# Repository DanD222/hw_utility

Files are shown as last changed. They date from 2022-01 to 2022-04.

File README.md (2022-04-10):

# PCB design for utility module
Utility hardware design for Audio Module, Analog Inputs, I2C/SPI sensors, RS232 and some digitial inputs. 
- PCB assembly files are below pcb/assembly/
- PDF Schematic is below pcb/pdf_exports/ 

## Components
- STM32F103 Bluepill board.
- 9 to 30V DC DC power supply.
- PAM8302AAS  audio amplifier connected to STM32F1 PWM output
- Screwterminal for loudspeaker
- RJ45 connector for sensing e.g. gear, flaps, airbrakes postion
- RJ45 connector for CAN Interface and CAN transceiver
- RJ12 connector with analog and digital inputs
- 1.27mm pitch header for external I2C devices
- 1.27mm pitch header for RS232 and SPI interface

## Pictures
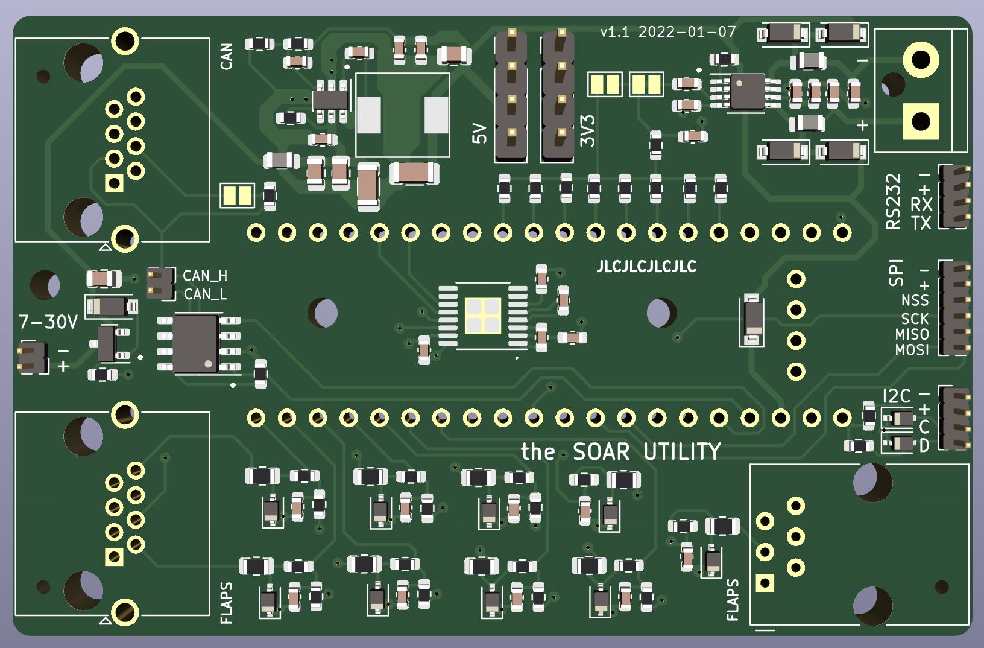
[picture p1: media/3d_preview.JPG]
3D Preview


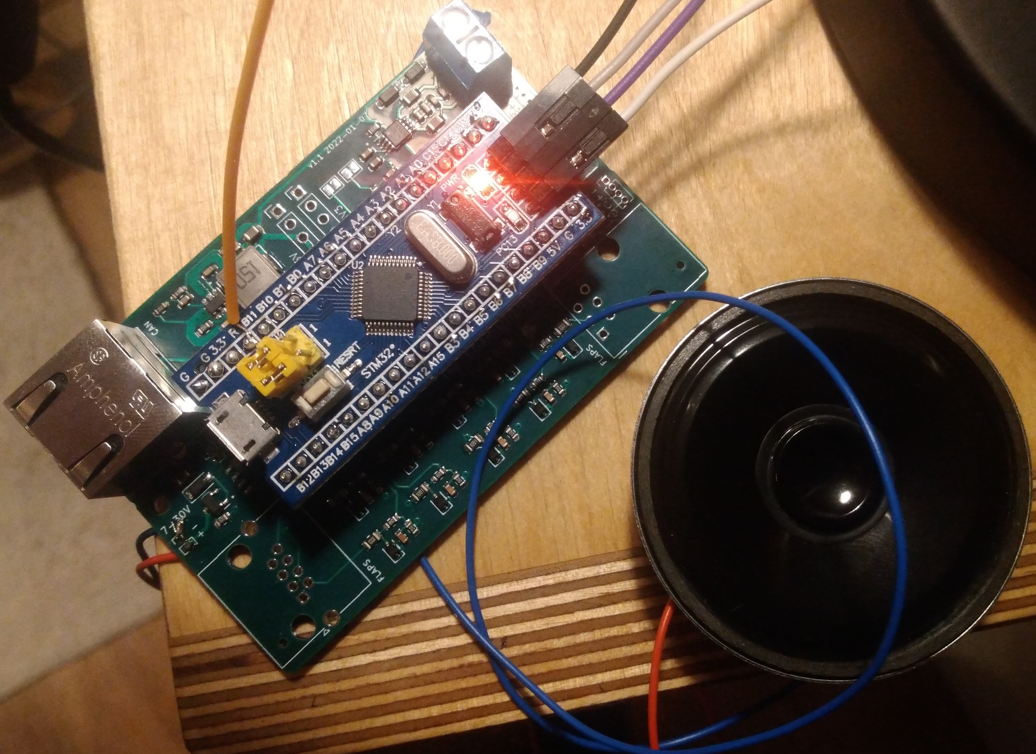
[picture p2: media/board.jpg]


## Improvements for next version
- External connectors for voltage / I2C / RS232 are tiny.  Increase size to e.g. 2.54mm pitch or chose a different connector.
- Make external i2c sensor voltage switchable to be able to perform a hard sensor reset. 
- Replace C32 47uF with a sufficient voltage rating. The used one is only specified for up to 10V!

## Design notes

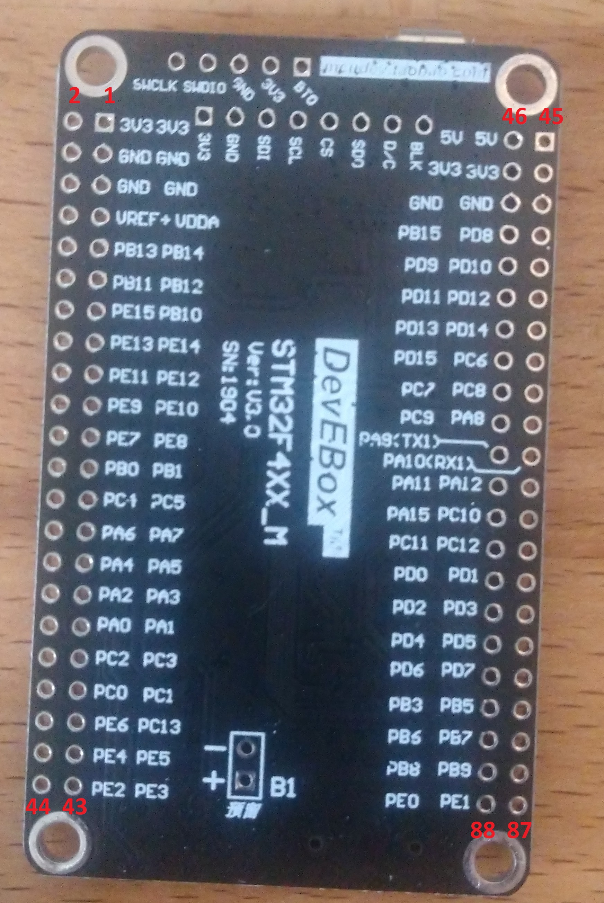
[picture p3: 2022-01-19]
parts/pinout.jpg

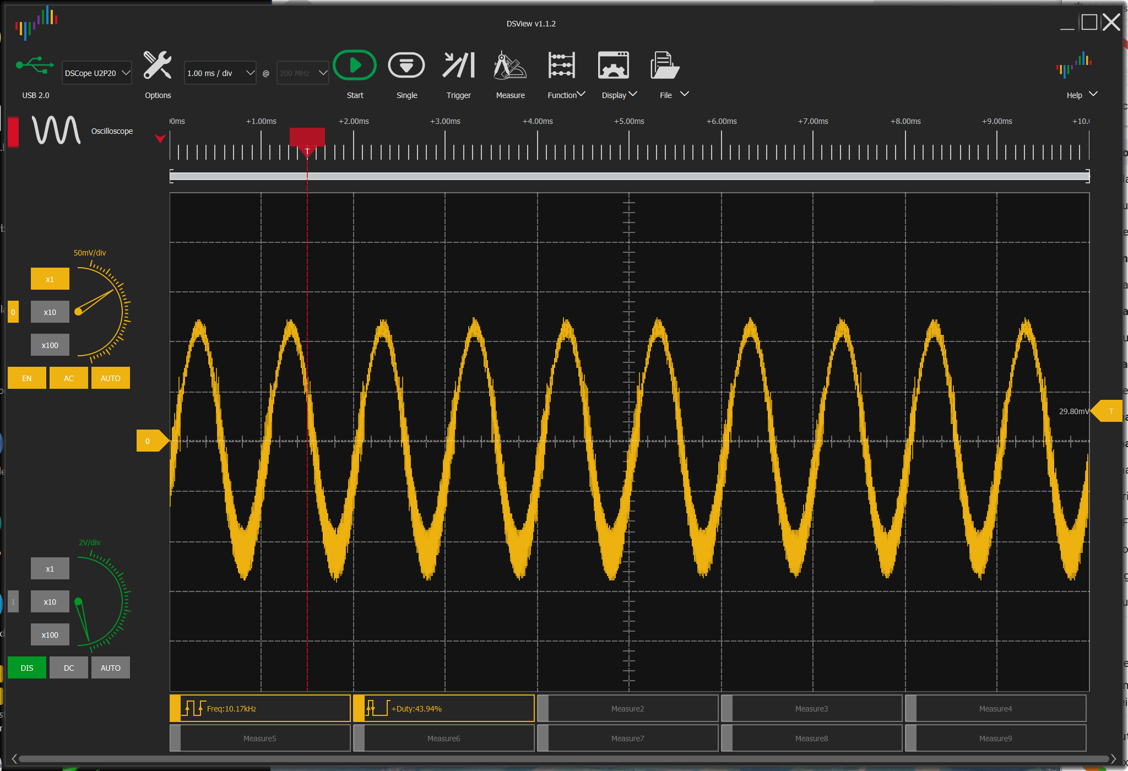
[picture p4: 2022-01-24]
media/1Khz_Sine_with_PWM.png

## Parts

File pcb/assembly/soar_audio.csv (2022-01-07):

Comment | Designator | Footprint | LCSC Part Number
10u | C1,C2,C9 | Capacitor_SMD:C_0805_2012Metric | C440198
10u | C13 | Capacitor_SMD:C_0603_1608Metric | C19702
220p | C15,C16 | Capacitor_SMD:C_0603_1608Metric | C1603
2n7 | C23 | Capacitor_SMD:C_0603_1608Metric | C1609
100n | C3,C7,C10,C24,C25,C27,C28,C29 | Capacitor_SMD:C_0603_1608Metric | C14663
100p | C30 | Capacitor_SMD:C_0603_1608Metric | C14858
47u | C31,C32 | Capacitor_SMD:C_1206_3216Metric | C96123
2u2 | C4 | Capacitor_SMD:C_0805_2012Metric | C49217
10n | C5,C6,C17,C18,C19,C20,C21,C22,C26 | Capacitor_SMD:C_0603_1608Metric | C57112
1u | C8,C11,C12,C14 | Capacitor_SMD:C_0603_1608Metric | C15849
D_MM1Z15 | D1 | Diode_SMD:D_SOD-123 | C86235
D_TVS | D2,D4,D5,D6,D12,D13,D14,D15,D16,D17,D21 | Diode_SMD:D_SOD-323 | C51450
D_B5819W | D7,D8,D9,D10,D11 | Diode_SMD:D_SOD-123 | C8598
Ferrite | FB1,FB3,FB4 | Inductor_SMD:L_0805_2012Metric | C1017
RJ45-FLAPS | J1 | RJ45_Amphenol_RJHSE5380
HEADER_6 | J11 | Connector_PinHeader_1.27mm:PinHeader_1x06_P1.27mm_Vertical
RJ12-FLAPS | J2 | Connector_RJ:RJ12_Amphenol_54601
HEADER_4 | J3,J6 | Connector_PinHeader_1.27mm:PinHeader_1x04_P1.27mm_Vertical
Screw_Terminal_01x02 | J4 | TerminalBlock:TerminalBlock_bornier-2_P5.08mm
RJ45-CAN | J5 | RJ45_Amphenol_RJHSE5380
HEADER_2 | J7,J10 | Connector_PinHeader_1.27mm:PinHeader_1x02_P1.27mm_Vertical
HEADER_4 | J8,J9 | Connector_PinHeader_2.54mm:PinHeader_1x04_P2.54mm_Vertical
Jumper_Bridged | JP1 | Jumper:SolderJumper-2_P1.3mm_Bridged_Pad1.0x1.5mm
Jumper_Open | JP2,JP5 | Jumper:SolderJumper-2_P1.3mm_Open_Pad1.0x1.5mm
15u | L1 | OWN_PARTS:SLO0630H | C182182
AO3401A | Q1 | Package_TO_SOT_SMD:SOT-23 | C15127
100k | R1,R4,R11,R19,R24,R25,R28,R31,R34 | Resistor_SMD:R_0603_1608Metric | C25803
0R | R10 | Resistor_SMD:R_0603_1608Metric | C21189
10k | R13 | Resistor_SMD:R_0603_1608Metric | C25804
R120 | R14 | Resistor_SMD:R_0603_1608Metric | C22787
4k7 | R15,R16 | Resistor_SMD:R_0603_1608Metric | C23162
1k | R2,R7,R17,R20,R21,R26,R29,R32,R44 | Resistor_SMD:R_0805_2012Metric | C17513
1k | R3,R8,R18,R22,R23,R27,R30,R33,R45 | Resistor_SMD:R_0603_1608Metric | C21190
120k | R35,R36 | Resistor_SMD:R_0603_1608Metric | C25808
56k | R37 | Resistor_SMD:R_0603_1608Metric | C23206
30k | R38 | Resistor_SMD:R_0603_1608Metric | C22984
15k | R39 | Resistor_SMD:R_0603_1608Metric | C22809
7k5 | R40 | Resistor_SMD:R_0603_1608Metric | C23234
3k6 | R41 | Resistor_SMD:R_0603_1608Metric | C22980
1k8 | R42 | Resistor_SMD:R_0603_1608Metric | C4177
105k | R5 | Resistor_SMD:R_0603_1608Metric | C16840
20k | R6 | Resistor_SMD:R_0603_1608Metric | C4184
68k | R9 | Resistor_SMD:R_0603_1608Metric | C23231
SCT2400 | U1 | Package_TO_SOT_SMD:TSOT-23-6 | C2693819
MAX3232 | U2 | Package_SO:HTSSOP-16-1EP_4.4x5mm_P0.65mm_EP3x3mm | C11317
SN65HVD231 | U3 | Package_SO:SOIC-8_3.9x4.9mm_P1.27mm | C129257
PAM8302AAS | U4 | Package_SO:MSOP-8_3x3mm_P0.65mm | C113367
BP | U6 | Bluepill:blue_pill

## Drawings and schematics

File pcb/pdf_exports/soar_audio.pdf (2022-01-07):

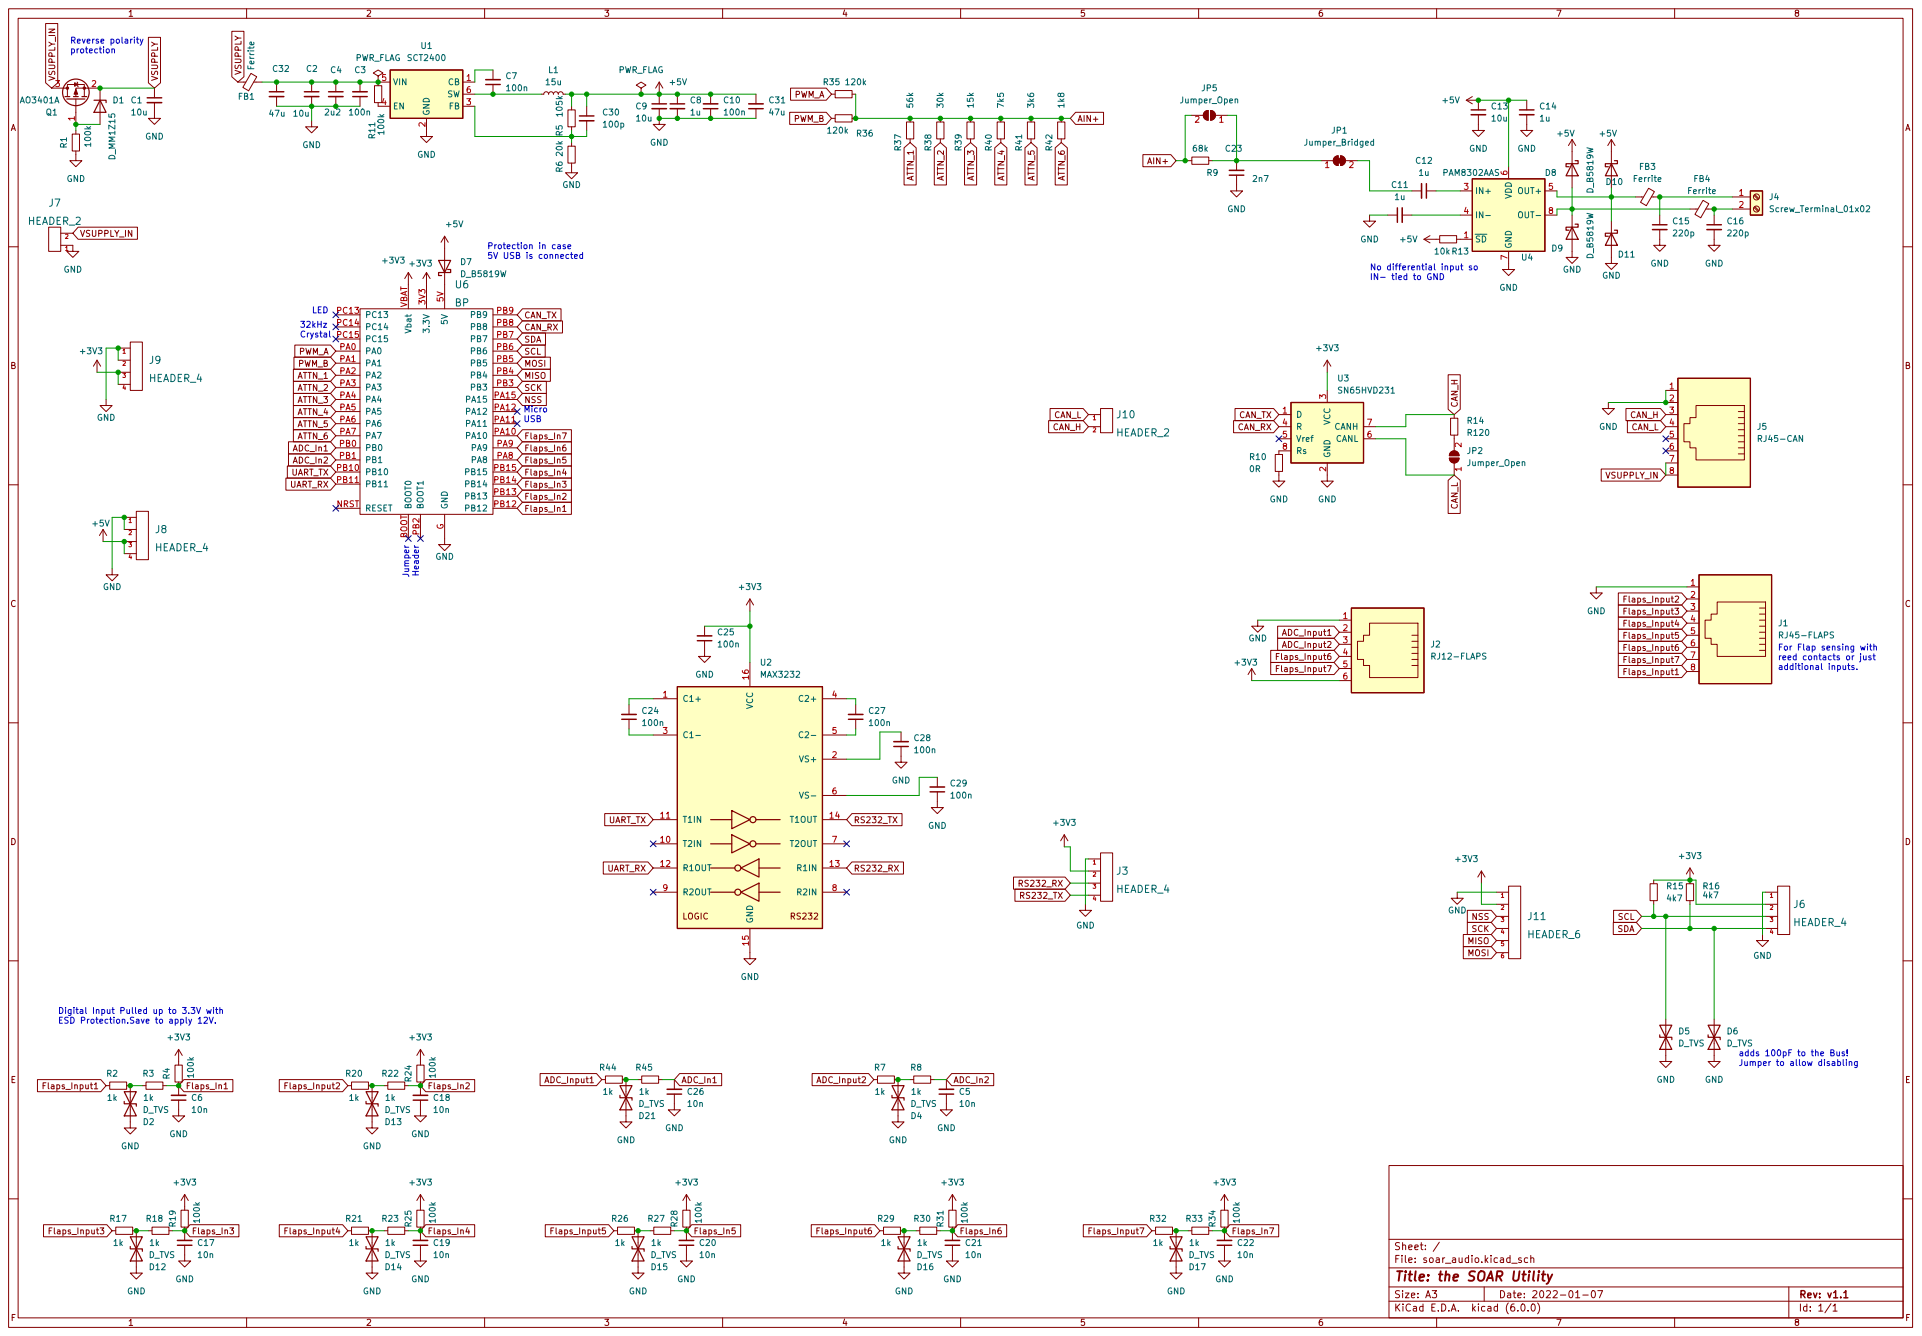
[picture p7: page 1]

2 FB 3 EN 4 VIN 5 SW 6 U1 SCT2400 C2

Protection in case 5V USB is connected
SCL SCK CAN_RX MOSI SDA CAN_TX

No differential input so
IN- tied to GND

additional inputs. Jumper Header

For Flap sensing with
reed contacts or just

ESD Protection.Save to apply 12V.

adds 100pF to the Bus!
Jumper to allow disabling

File: soar_audio.kicad_sch Sheet: /
Id: 1/1 Title: the SOAR Utility

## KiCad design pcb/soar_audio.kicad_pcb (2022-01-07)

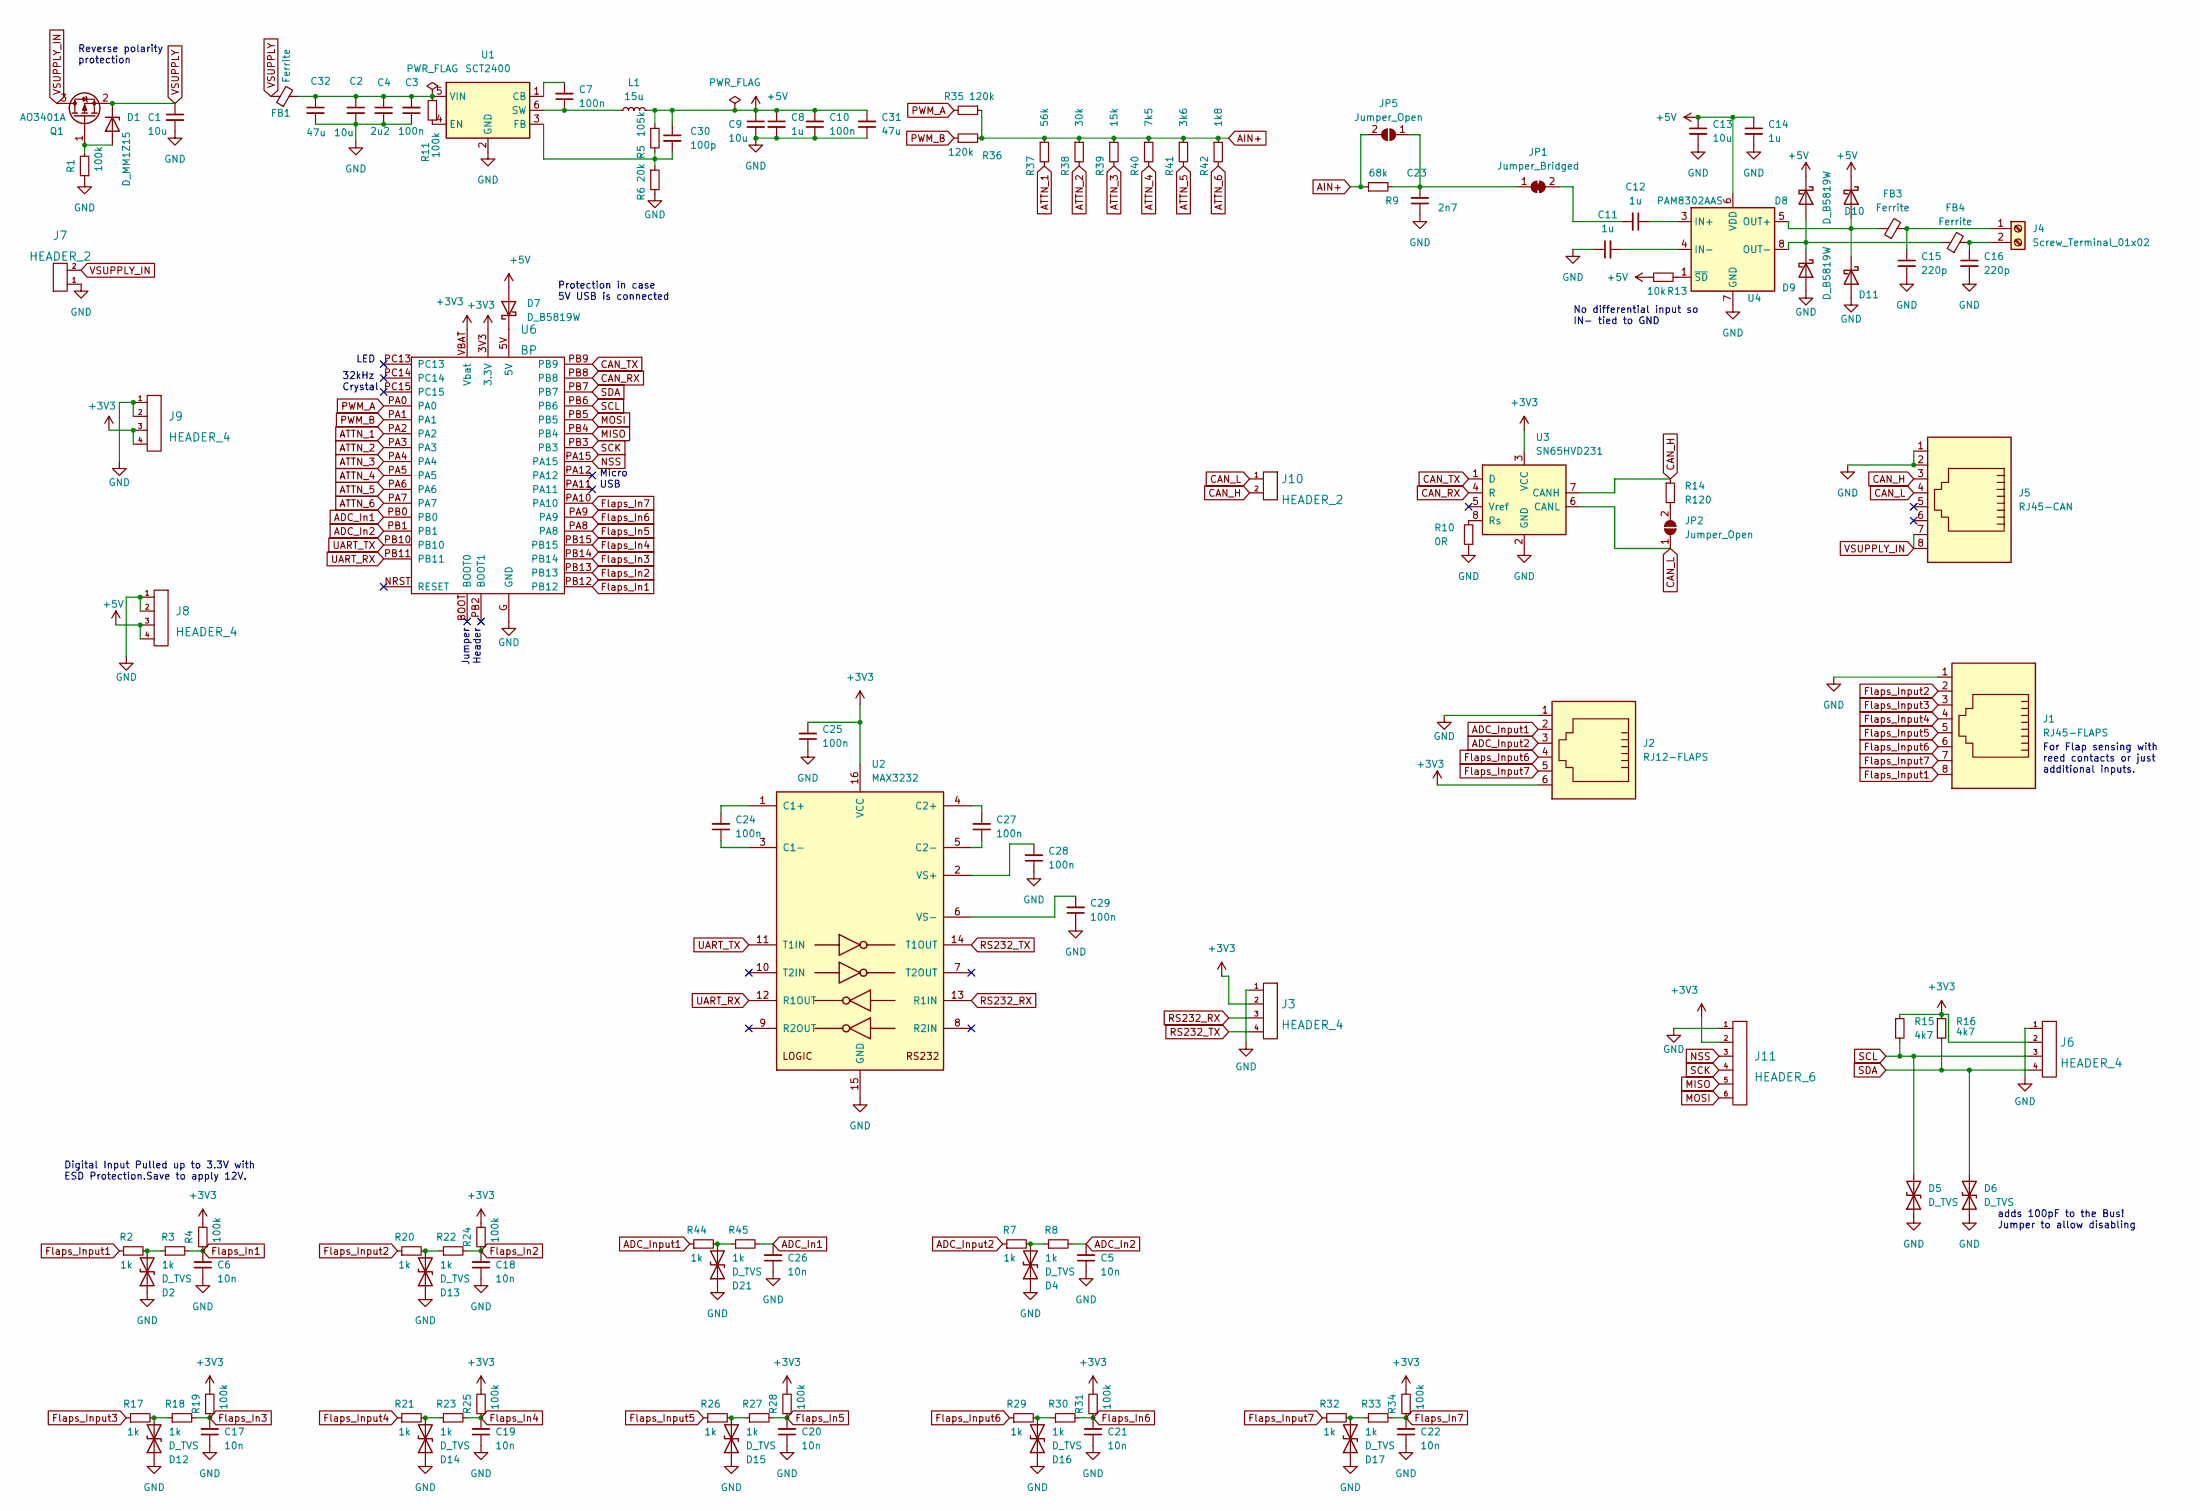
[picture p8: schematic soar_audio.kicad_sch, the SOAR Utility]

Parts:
C1, C2, C9: 10u; C_0805_2012Metric; LCSC C440198
C3, C7, C10, C24, C25, C27, C28, C29: 100n; C_0603_1608Metric; LCSC C14663
C4: 2u2; C_0805_2012Metric; LCSC C49217
C5, C6, C17, C18, C19, C20, C21, C22, C26: 10n; C_0603_1608Metric; LCSC C57112
C8, C11, C12, C14: 1u; C_0603_1608Metric; LCSC C15849
C13: 10u; C_0603_1608Metric; LCSC C19702
C15, C16: 220p; C_0603_1608Metric; LCSC C1603
C23: 2n7; C_0603_1608Metric; LCSC C1609
C30: 100p; C_0603_1608Metric; LCSC C14858
C31, C32: 47u; C_1206_3216Metric; LCSC C96123
D1: D_MM1Z15; D_SOD-123; LCSC C86235
D2, D4, D5, D6, D12, D13, D14, D15, D16, D17, D21: D_TVS; D_SOD-323; LCSC C51450
D7, D8, D9, D10, D11: D_B5819W; D_SOD-123; LCSC C8598
FB1, FB3, FB4: Ferrite; L_0805_2012Metric; LCSC C1017
J1: RJ45-FLAPS; RJ45_Amphenol_RJHSE5380
J2: RJ12-FLAPS; RJ12_Amphenol_54601
J3, J6: HEADER_4; PinHeader_1x04_P1.27mm_Vertical
J4: Screw_Terminal_01x02; TerminalBlock_bornier-2_P5.08mm
J5: RJ45-CAN; RJ45_Amphenol_RJHSE5380
J7, J10: HEADER_2; PinHeader_1x02_P1.27mm_Vertical
J8, J9: HEADER_4; PinHeader_1x04_P2.54mm_Vertical
J11: HEADER_6; PinHeader_1x06_P1.27mm_Vertical
JP1: Jumper_Bridged; SolderJumper-2_P1.3mm_Bridged_Pad1.0x1.5mm
JP2, JP5: Jumper_Open; SolderJumper-2_P1.3mm_Open_Pad1.0x1.5mm
L1: 15u; SLO0630H; LCSC C182182
Q1: AO3401A; SOT-23; LCSC C15127
R1, R4, R11, R19, R24, R25, R28, R31, R34: 100k; R_0603_1608Metric; LCSC C25803
R2, R7, R17, R20, R21, R26, R29, R32, R44: 1k; R_0805_2012Metric; LCSC C17513
R3, R8, R18, R22, R23, R27, R30, R33, R45: 1k; R_0603_1608Metric; LCSC C21190
R5: 105k; R_0603_1608Metric; LCSC C16840
R6: 20k; R_0603_1608Metric; LCSC C4184
R9: 68k; R_0603_1608Metric; LCSC C23231
R10: 0R; R_0603_1608Metric; LCSC C21189
R13: 10k; R_0603_1608Metric; LCSC C25804
R14: R120; R_0603_1608Metric; LCSC C22787
R15, R16: 4k7; R_0603_1608Metric; LCSC C23162
R35, R36: 120k; R_0603_1608Metric; LCSC C25808
R37: 56k; R_0603_1608Metric; LCSC C23206
R38: 30k; R_0603_1608Metric; LCSC C22984
R39: 15k; R_0603_1608Metric; LCSC C22809
R40: 7k5; R_0603_1608Metric; LCSC C23234
R41: 3k6; R_0603_1608Metric; LCSC C22980
R42: 1k8; R_0603_1608Metric; LCSC C4177
U1: SCT2400; TSOT-23-6; LCSC C2693819
U2: MAX3232; HTSSOP-16-1EP_4.4x5mm_P0.65mm_EP3x3mm; LCSC C11317
U3: SN65HVD231; SOIC-8_3.9x4.9mm_P1.27mm; LCSC C129257
U4: PAM8302AAS; MSOP-8_3x3mm_P0.65mm; LCSC C113367
U6: BP; blue_pill

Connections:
+3V3: C25.2, J2.6, J3.2, J6.2, J9.3, J9.4, J11.2, R4.2, R15.1, R16.1, R19.2, R24.2, R25.2, R28.2, R31.2, R34.2, U2.16 (VCC), U3.3 (VCC), U6.3V3 (3.3V), U6.VBAT (Vbat)
+5V: C8.1, C9.1, C10.2, C13.1, C14.1, C30.1, C31.2, D7.2 (A), D8.1 (K), D10.1 (K), J8.3, J8.4, L1.2, R5.1, R13.1, U4.6 (VDD)
ADC_In1: C26.2, R45.2, U6.PB0
ADC_In2: C5.2, R8.2, U6.PB1
ADC_Input1: J2.2, R44.1
ADC_Input2: J2.3, R7.1
AIN+: JP5.2 (B), R9.1, R35.1, R36.2, R37.1, R38.1, R39.1, R40.1, R41.1, R42.1
ATTN_1: R37.2, U6.PA2
ATTN_2: R38.2, U6.PA3
ATTN_3: R39.2, U6.PA4
ATTN_4: R40.2, U6.PA5
ATTN_5: R41.2, U6.PA6
ATTN_6: R42.2, U6.PA7
CAN_H: J5.3, J10.2, R14.1, U3.7 (CANH)
CAN_L: J5.4, J10.1, JP2.1 (A), U3.6 (CANL)
CAN_RX: U3.4 (R), U6.PB8
CAN_TX: U3.1 (D), U6.PB9
Flaps_In1: C6.2, R3.2, R4.1, U6.PB12
Flaps_In2: C18.2, R22.2, R24.1, U6.PB13
Flaps_In3: C17.2, R18.2, R19.1, U6.PB14
Flaps_In4: C19.2, R23.2, R25.1, U6.PB15
Flaps_In5: C20.2, R27.2, R28.1, U6.PA8
Flaps_In6: C21.2, R30.2, R31.1, U6.PA9
Flaps_In7: C22.2, R33.2, R34.1, U6.PA10
Flaps_Input1: J1.8, R2.1
Flaps_Input2: J1.2, R20.1
Flaps_Input3: J1.3, R17.1
Flaps_Input4: J1.4, R21.1
Flaps_Input5: J1.5, R26.1
Flaps_Input6: J1.6, J2.4, R29.1
Flaps_Input7: J1.7, J2.5, R32.1
GND: C1.2, C2.2, C3.1, C4.2, C5.1, C6.1, C8.2, C9.2, C10.1, C11.1, C13.2, C14.2, C15.2, C16.2, C17.1, C18.1, C19.1, C20.1, C21.1, C22.1, C23.1, C25.1, C26.1, C28.1, C29.1, C31.1, C32.2, D2.1 (A1), D4.1 (A1), D5.1 (A1), D6.1 (A1), D9.2 (A), D11.2 (A), D12.1 (A1), D13.1 (A1), D14.1 (A1), D15.1 (A1), D16.1 (A1), D17.1 (A1), D21.1 (A1), J1.1, J2.1, J3.1, J5.1, J5.2, J6.1, J7.1, J8.1, J8.2, J9.1, J9.2, J11.1, R1.1, R6.2, R10.1, U1.2 (GND), U2.15 (GND), U3.2 (GND), U4.7 (GND), U6.G (GND)
MISO: J11.5, U6.PB4
MOSI: J11.6, U6.PB5
NSS: J11.3, U6.PA15
unnamed: C2.1, C3.2, C4.1, C32.1, FB1.2, R11.2, U1.5 (VIN)
unnamed: C7.1, L1.1, U1.6 (SW)
unnamed: C7.2, U1.1 (CB)
unnamed: C11.2, U4.4 (IN-)
unnamed: C12.1, U4.3 (IN+)
unnamed: C12.2, JP1.2 (B)
unnamed: C15.1, FB3.2, J4.1
unnamed: C16.1, FB4.2, J4.2
unnamed: C23.2, JP1.1 (A), JP5.1 (A), R9.2
unnamed: C24.1, U2.3 (C1-)
unnamed: C24.2, U2.1 (C1+)
unnamed: C27.1, U2.5 (C2-)
unnamed: C27.2, U2.4 (C2+)
unnamed: C28.2, U2.2 (VS+)
unnamed: C29.2, U2.6 (VS-)
unnamed: D1.2 (A), Q1.1 (G), R1.2
unnamed: D2.2 (A2), R2.2, R3.1
unnamed: D4.2 (A2), R7.2, R8.1
unnamed: D7.1 (K), U6.5V
unnamed: D8.2 (A), D9.1 (K), FB4.1, U4.8 (OUT-)
unnamed: D10.2 (A), D11.1 (K), FB3.1, U4.5 (OUT+)
unnamed: D12.2 (A2), R17.2, R18.1
unnamed: D13.2 (A2), R20.2, R22.1
unnamed: D14.2 (A2), R21.2, R23.1
unnamed: D15.2 (A2), R26.2, R27.1
unnamed: D16.2 (A2), R29.2, R30.1
unnamed: D17.2 (A2), R32.2, R33.1
unnamed: D21.2 (A2), R44.2, R45.1
unnamed: JP2.2 (B), R14.2
unnamed: C30.2, R5.2, R6.1, U1.3 (FB)
unnamed: R10.2, U3.8 (Rs)
unnamed: R13.2, U4.1 (~SD)
unnamed: R11.1, U1.4 (EN)
PWM_A: R35.2, U6.PA0
PWM_B: R36.1, U6.PA1
RS232_RX: J3.3, U2.13 (R1IN)
RS232_TX: J3.4, U2.14 (T1OUT)
SCK: J11.4, U6.PB3
SCL: D5.2 (A2), J6.3, R15.2, U6.PB6
SDA: D6.2 (A2), J6.4, R16.2, U6.PB7
UART_RX: U2.12 (R1OUT), U6.PB11
UART_TX: U2.11 (T1IN), U6.PB10
VSUPPLY: C1.1, D1.1 (K), FB1.1, Q1.2 (S)
VSUPPLY_IN: J5.7, J5.8, J7.2, Q1.3 (D)

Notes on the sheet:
Protection in case 5V USB is connected
Micro USB
32kHz Crystal
adds 100pF to the Bus! Jumper to allow disabling
Jumper Header
Reverse polarity protection
No differential input so IN- tied to GND
Digital Input Pulled up to 3.3V with ESD Protection.Save to apply 12V.
For Flap sensing with reed contacts or just additional inputs.
LED

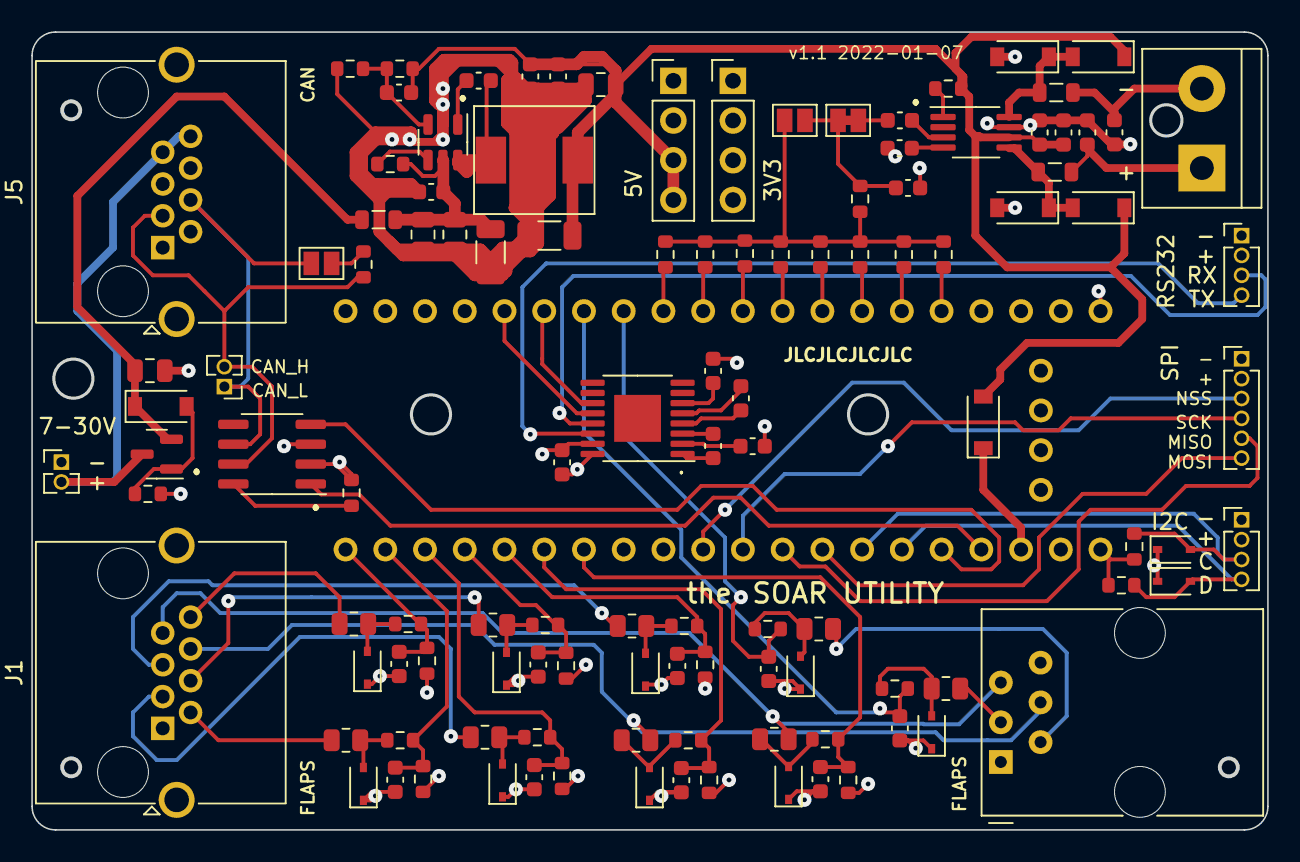
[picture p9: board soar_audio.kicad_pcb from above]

Board: 4 copper layers, 79.0 x 51.0 mm, 116 parts (0 on the bottom side), 79 nets.

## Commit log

2022-01-02 initial creation
    [audio.sch]
2022-01-03 started creating pcb
    [soar_audio.kicad_pcb, soar_audio.kicad_sch]
2022-01-03 added dcdc power supply
    [soar_audio.kicad_sch]
2022-01-03 added 3v3 power supply
    [soar_audio.kicad_sch]
2022-01-04 updated with bluepill and discovery board footprint
    [soar_audio.kicad_pcb, soar_audio.kicad_sch]
2022-01-04 updated schematic and layout
    [soar_audio.kicad_pcb, soar_audio.kicad_sch]
2022-01-04 updated jlc rules to layout
    [soar_audio.kicad_pcb, soar_audio.kicad_sch]
2022-01-04 some more steps done
    [soar_audio.kicad_pcb, soar_audio.kicad_sch]
2022-01-05 add toolingholes
    [soar_audio.kicad_pcb, soar_audio.kicad_sch]
2022-01-05 finalized pcb
    [soar_audio.kicad_pcb]
2022-01-05 generated gerber files
    [soar_audio-B_Cu.gbl, soar_audio-B_Mask.gbs, soar_audio-B_Paste.gbp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]
2022-01-05 generated all assembly files
    [soar_audio.csv, soar_audio.kicad_pcb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]
2022-01-05 replaced out of stock inductor
    [soar_audio-B_Cu.gbl, soar_audio-B_Mask.gbs, soar_audio-B_Paste.gbp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]
2022-01-05 add footprint for L
2022-01-05 corrected footprint position file
    [soar_audio-top-pos.csv]
2022-01-05 some minor changes
    [soar_audio.kicad_pcb, soar_audio.kicad_sch]
2022-01-06 updates based on feedback from Klaus
    [soar_audio.kicad_pcb, soar_audio.kicad_sch]
2022-01-06 finalized pcb and generated v1.0 production files
    [soar_audio-B_Cu.gbl, soar_audio-B_Mask.gbs, soar_audio-B_Paste.gbp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]
2022-01-06 corrected part roations
    [soar_audio-top-pos.csv]
2022-01-06 final ordered version 1.0
    [soar_audio-B_Cu.gbl, soar_audio-B_Mask.gbs, soar_audio-B_Paste.gbp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]
2022-01-07 changed dc-dc converter
    [soar_audio-B_Cu.gbl, soar_audio-B_Mask.gbs, soar_audio-B_Paste.gbp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]
